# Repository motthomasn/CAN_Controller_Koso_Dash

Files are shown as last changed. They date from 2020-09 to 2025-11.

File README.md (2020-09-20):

# CAN_Controller_Koso_Dash
Teensy 3.2 based controller board designed to recieve engine data from ECU via CAN-Bus and use it to control a Koso RX2N motorcycle dash

This module was built for my CBR250RRi project. The aim was to run my aftermarket Koso RX2N dash using the same sensors (coolant & oil temp) as the ECU to avoid having to double up on sensors. The idea was to recieve all necessary signals from the ECU via CAN-Bus and then have the Teensy replicate the analogue signals that the dash expects.

The Koso RX2N dash has the following possible inputs for indication:
1. Engine speed         - variable frequency square wave signal
1. Vehicle speed        - variable frequency square wave signal
1. Coolant temperature  - thermistor
1. Oil temperature      - thermistor
1. Oil pressure light   - digital on/off signal, low side switch
1. EOBD light           - digital on/off signal, low side switch
1. Neutral light        - digital on/off signal, low side switch
1. Fuel level           - digital on/off signal, low side switch
1. Hi-beam light        - digital on/off signal, high side switch
1. RH Indicator         - digital on/off signal, high side switch
1. LH Indicator         - digital on/off signal, high side switch

The LH/RH indicators, hi-beam, fuel level & neutral signals were all provided directly from the sensors and wire harness. All other signals relied on sensors which would be connected directly to the ECU and therefore required the controller to provide the signals based on data recieved via CAN-Bus.

**Engine & Vehicle Speed**
Although the ECU could provide the required signal directly to the dash using an injector output, I decided to save the ECU output and hand the job over to the dash controller. A 50% duty cycle variable frequency signal is provided by the Teensy switching 12V to gound. The frequency is updated at 50Hz to avoid visible stuttering of the dash needle during fast engine speed ramps. 
A similar tactic as engine speed was employed to the vehicle speed signal apart from the signal being 5V level and the signal frequency is updated at only 5Hz as vehicle speed is displayed on a 7-segment display. 

**Coolant & Oil Temperature**
A pair of digital potentiometers are employed to replicate the thermistor resistance. The R-T curve for the sensors supplied with the RX2N had been provided by Koso tech support. The linear response and resolution of the digital potentiometers means that there could be an error of up to 3°C between the actual and displayed values between 90-110°C temperature. The dash display is only an indication so this level of accuracy is acceptable.

**Oil Pressure Light**
My bike and most others from the 1990's came fitted with an oil pressure switch. The original switch could be connected directly to the dash but as I have replaced the pressure switch with an actual pressure sensor, I have added the possibility of controlling the light via the dash controller. In the current version of the code, the actual oil pressure is compared to a single threshold, so operates the light much the same as the original switch. I plan to update the code to add a varying pressure threshold with engine speed and oil temperature after I have collected some data to build a normal oil pressure map.

**EOBD Light**
The EOBD light is a handy indicator of something being wrong on the ECU side. The measure of "something wrong" depends on the ECU but on my Life Racing F88R I use a flag called *engineEnable* and set the EOBD light if the flag is not equal to 0 (OK).

I included tracks on the controller board for USB to allow the Teensy code to be updated without opening the enclosure. However, I did not adhere to recommendations around USB bus design and so this does not work. I plan to update the board to meet guidelines in the future.

For further details on the CBR250RRi project, refer to the website https://www.cbr250rri.com/.

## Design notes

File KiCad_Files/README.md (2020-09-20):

This folder contains the KiCad files for the Dash Controller Module

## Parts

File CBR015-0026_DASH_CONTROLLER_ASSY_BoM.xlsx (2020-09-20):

Designation | Qty | Description | Value | Manufacturer | Part Number | Package | Supplier | Stock No. / Order Code | Notes | Datasheet
U1 | 1 | Teensy 3.2 |  | PJRC | Teensy 3.2 | PDIP
 | 2 | Teensy Pin Header | 14-way, 2.54mm |  |  |  | RS
 | 2 | Teensy Connector Socket | 14-way, 2.54mm |  |  |  | RS
 | 1 | Teensy USB Pin Header |  |  |  |  | RS
 | 1 | Teensy USB Connector Socket |  |  |  |  | RS
U2 | 1 | 5V Power Regulator | 5V, 1A | Traco Power | TSR-1-2450 | SIP3 | RS | 666-4379
U3 | 1 | CAN Transciever |  | Microchip | MCP2551-I/SN | SOIC-8 | RS | 738-6036
U4 | 1 | Digital Potentiometer | 250K, 1024-posn | Analog Devices | AD5235BRUZ250 | TSSOP-16 | RS | 497-0751
U5, U6 | 2 | Dash Signal & Shift Light Switches | NPN, 40V, 200mA | ON Semiconductor | MMPQ3904 | SOIC-16 | RS | 807-4863
C1 | 1 | Power Reg Cap | 22uF | Murata | GRM219B30G226ME66D | 0805 | RS | 798-4621
C2 | 1 | CAN Transciever Smoothing Cap | 100nF | AVX | 08055C104KAT2A | 0805 | RS | 464-6688
C3 | 1 | Digital Pot Smoothing Cap | 100nF | AVX | 08055C104KAT2A | 0805 | RS | 464-6688
R1 | 1 | CAN Transciever Reset | 18K | TE Connectivity | CRG0805F18K | 0805 | RS | 223-0590
R2 | 1 | CAN Termination | 120 | Panasonic | ERJP06F1200V | 0805 | RS | 721-7674
R3, R4, R5, R6, R7, R8, R13, R14 | 8 | BJT Base Current Limiters | 523 | Panasonic | ERA6AEB5230V | 0805 | RS | 708-6048
R9, R10 | 2 | VSS & TACH Pull-up Resistors | 10K | TE Connectivity | CRG0805F10K | 0805 | RS | 223-0562
R11, R12 | 2 | Pot RDY & CS Pull-up resistors | 2.2K | Vishay | CRCW08052K20FKEA | 0805 | RS | 679-1207
S1 | 1 | CAN Termination Jumper | Single SPST | APEM | IKD0103101 |  | RS | 877-2233
J1 | 1 | Harness Connector | Superseal 1.0, 26-way | TE Connectivity | 6437288-4 |  | RS | 726-7011

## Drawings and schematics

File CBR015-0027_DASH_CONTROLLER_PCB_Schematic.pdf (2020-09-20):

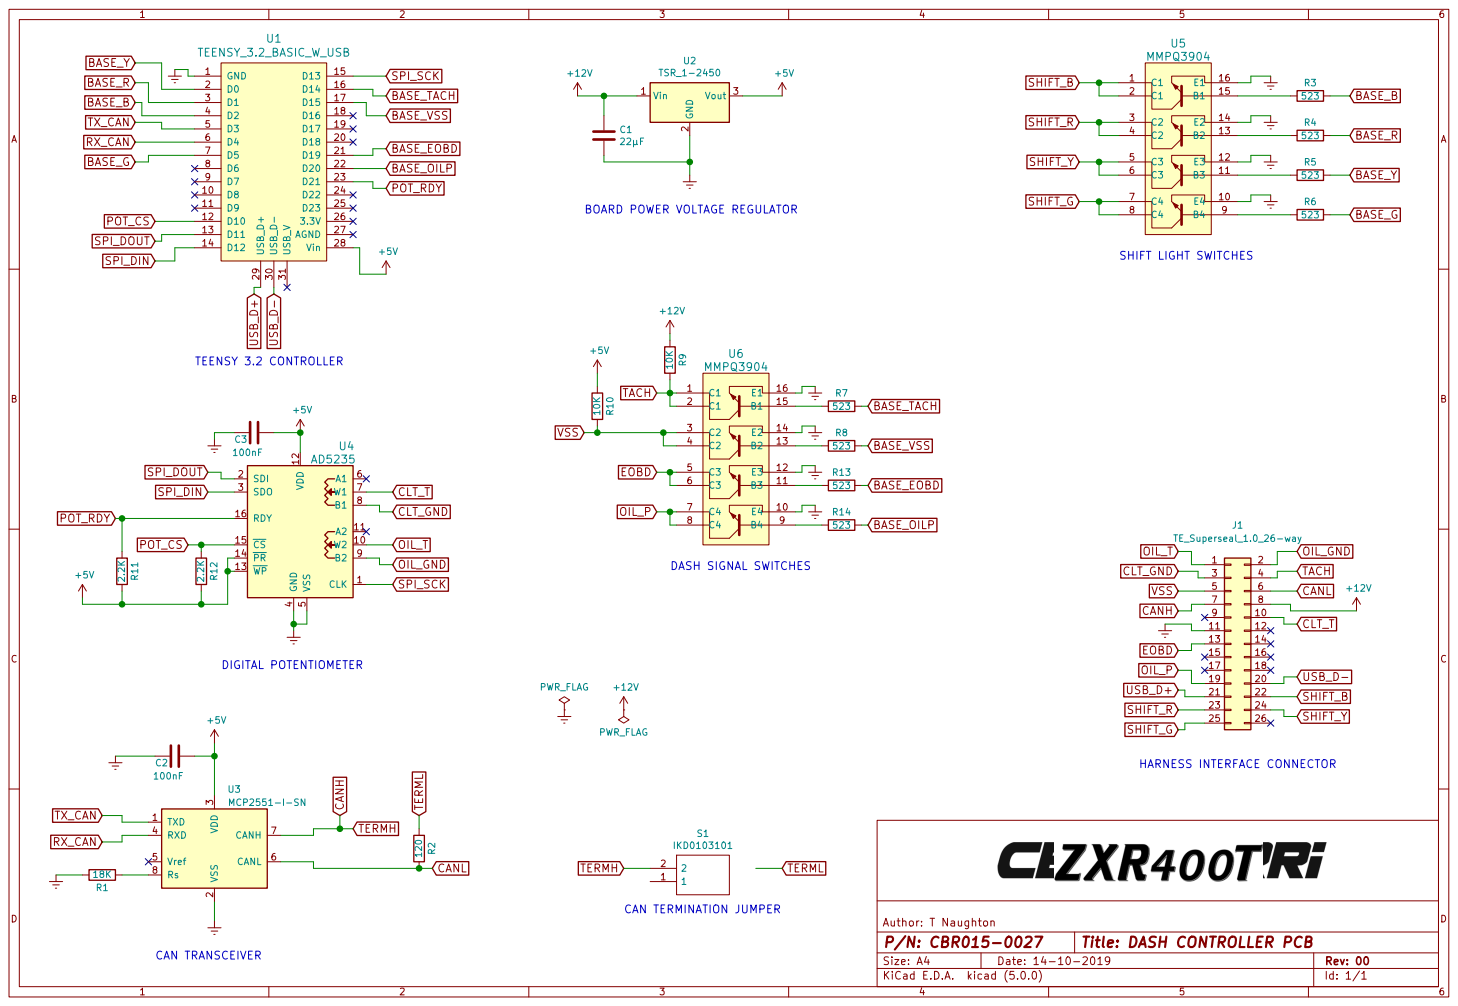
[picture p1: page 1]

BOARD POWER VOLTAGE REGULATOR

3 RXD 4 Vref 5 CANL 6 CANH 7 Rs 8 U3MCP2551-I-SN

Id: 1/1 Title: DASH CONTROLLER PCB

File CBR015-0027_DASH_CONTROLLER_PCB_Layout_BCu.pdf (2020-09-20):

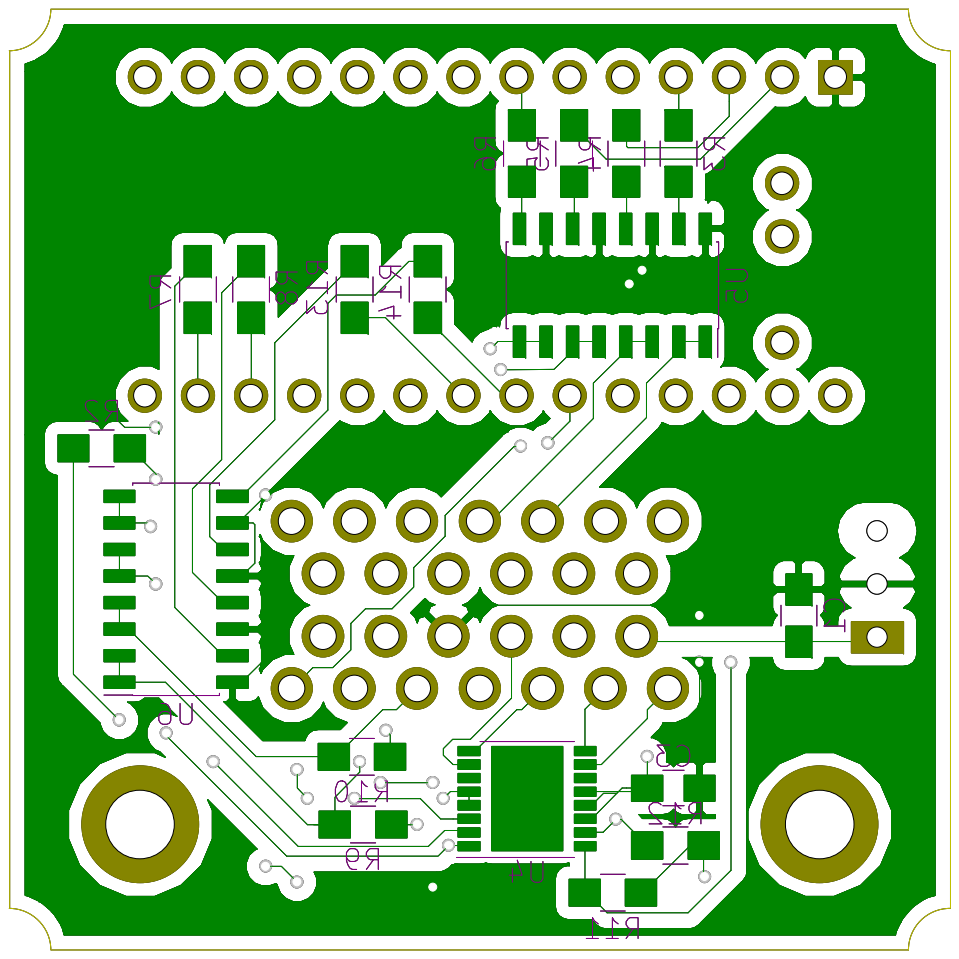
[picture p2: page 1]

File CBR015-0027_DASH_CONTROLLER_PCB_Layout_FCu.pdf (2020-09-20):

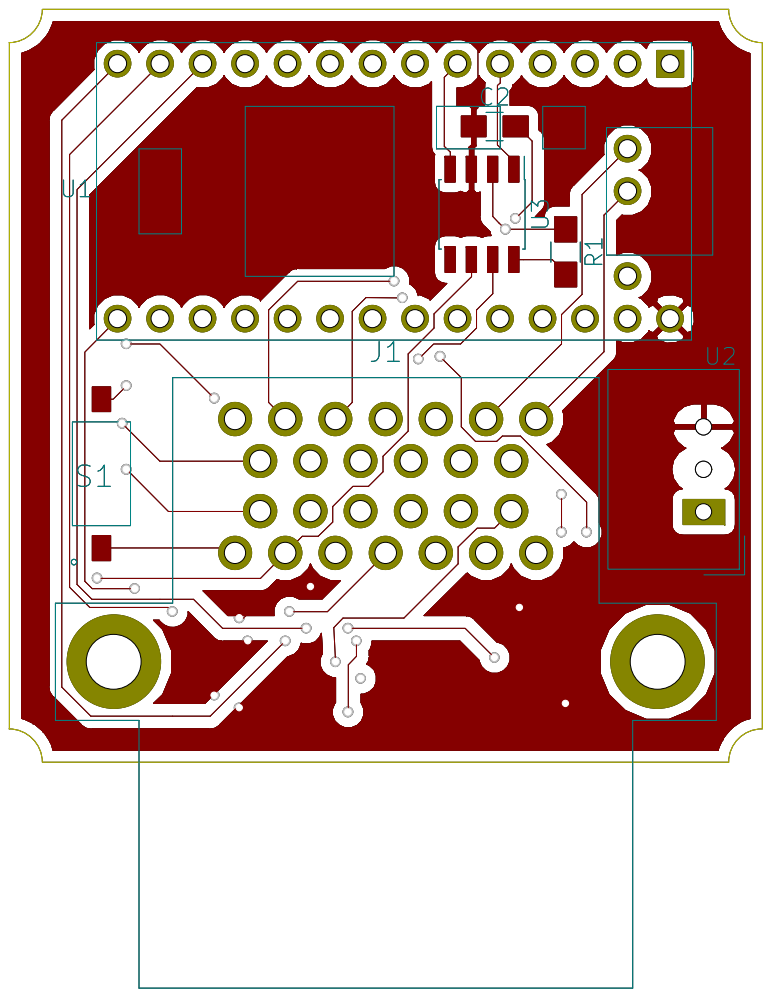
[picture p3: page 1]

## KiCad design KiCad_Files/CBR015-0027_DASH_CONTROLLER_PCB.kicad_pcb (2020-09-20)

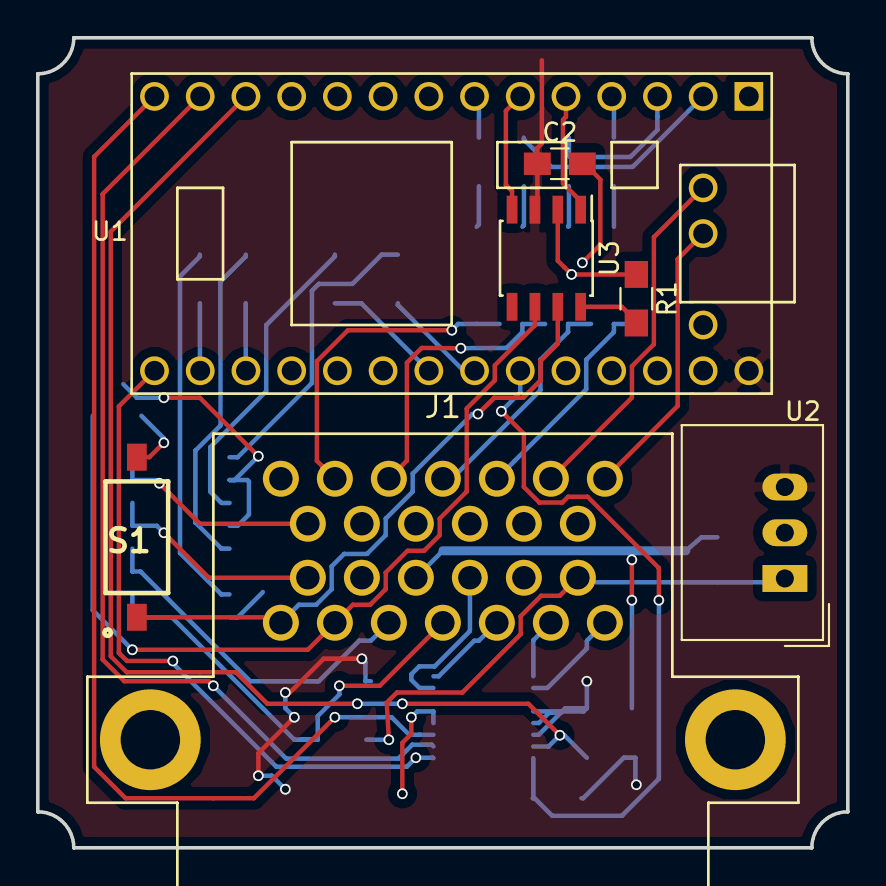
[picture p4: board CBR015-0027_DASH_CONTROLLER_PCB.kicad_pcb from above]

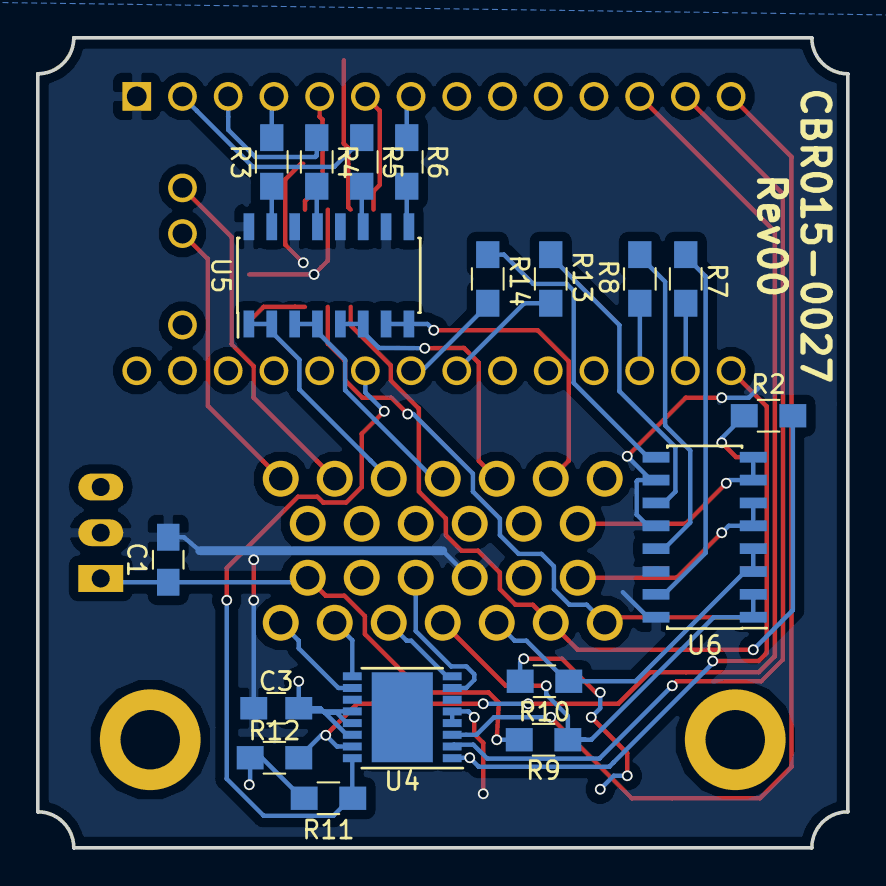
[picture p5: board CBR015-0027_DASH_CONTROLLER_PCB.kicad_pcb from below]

Board: 2 copper layers, 45.0 x 45.0 mm, 25 parts (18 on the bottom side), 44 nets.

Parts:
C1: 22µF; C_0805_HandSoldering
C2, C3: 100nF; C_0805_HandSoldering
J1: Conn_02x13_Odd_Even; TE_SUPERSEAL_1.0_26-WAY
R1: 18K; R_0805_HandSoldering
R2: 120; R_0805_HandSoldering
R3, R4, R5, R6, R7, R8, R13, R14: 523; R_0805_HandSoldering
R9, R10: 10K; R_0805_HandSoldering
R11, R12: 2.2K; R_0805_HandSoldering
S1: IKD0103101
U1: TEENSY_3.2_BASIC_W_USB
U2: TSR_1-2450; DCDC-Conv_TRACO_TSR-1
U3: MCP2551-I-SN; SOIC-8_3.9x4.9mm_Pitch1.27mm
U4: AD5235; HTSSOP-16-1EP_4.4x5mm_Pitch0.65mm
U5, U6: MMPQ3904; SOIC-16_3.9x9.9mm_Pitch1.27mm

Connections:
+5V: C2.1, C3.1, R10.2, R11.1, R12.1, U1.28, U2.3, U3.3, U4.12, U4.13, U4.14
+12V: C1.1, J1.8, R9.2, U2.1
BASE_B: R3.1, U1.4
BASE_EOBD: R13.1, U1.21
BASE_G: R6.1, U1.7
BASE_OILP: R14.1, U1.22
BASE_R: R4.1, U1.3
BASE_TACH: R7.1, U1.16
BASE_VSS: R8.1, U1.17
BASE_Y: R5.1, U1.2
CANH: J1.7, S1.1, U3.7
CANL: J1.6, R2.1, U3.6
CLT_GND: J1.3, U4.8
CLT_T: J1.10, U4.7
EOBD: J1.13, U6.5, U6.6
Earth: C1.2, C2.2, C3.2, J1.11, R1.1, U1.1, U2.2, U3.2, U4.4, U4.5, U5.10, U5.12, U5.14, U5.16, U6.10, U6.12, U6.14, U6.16
unnamed: R1.2, U3.8
unnamed: R3.2, U5.15
unnamed: R4.2, U5.13
unnamed: R5.2, U5.11
unnamed: R6.2, U5.9
unnamed: R7.2, U6.15
unnamed: R8.2, U6.13
unnamed: R13.2, U6.11
unnamed: R14.2, U6.9
OIL_GND: J1.2, U4.9
OIL_P: J1.19, U6.7, U6.8
OIL_T: J1.1, U4.10
POT_CS: R12.2, U1.12, U4.15
POT_RDY: R11.2, U1.23, U4.16
RX_CAN: U1.6, U3.4
SHIFT_B: J1.22, U5.1, U5.2
SHIFT_G: J1.25, U5.7, U5.8
SHIFT_R: J1.23, U5.3, U5.4
SHIFT_Y: J1.24, U5.5, U5.6
SPI_DIN: U1.14, U4.3
SPI_DOUT: U1.13, U4.2
SPI_SCK: U1.15, U4.1
TACH: J1.4, R9.1, U6.1, U6.2
TERML: R2.2, S1.2
TX_CAN: U1.5, U3.1
USB_D+: J1.21, U1.29
USB_D-: J1.20, U1.30
VSS: J1.5, R10.1, U6.3, U6.4

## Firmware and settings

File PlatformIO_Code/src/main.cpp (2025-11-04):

/*
 * Copyright 2020 THOMAS NAUGHTON
 * 
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
 * The above copyright notice and this permission notice shall be included in all copies or substantial portions of the Software.
 * 
 * THE SOFTWARE IS PROVIDED "AS IS", WITHOUT WARRANTY OF ANY KIND, EXPRESS OR IMPLIED, INCLUDING BUT NOT LIMITED TO THE WARRANTIES OF MERCHANTABILITY, 
 * FITNESS FOR A PARTICULAR PURPOSE AND NONINFRINGEMENT. IN NO EVENT SHALL THE AUTHORS OR COPYRIGHT HOLDERS BE LIABLE FOR ANY CLAIM, DAMAGES OR OTHER LIABILITY, 
 * WHETHER IN AN ACTION OF CONTRACT, TORT OR OTHERWISE, ARISING FROM, OUT OF OR IN CONNECTION WITH THE SOFTWARE OR THE USE OR OTHER DEALINGS IN THE SOFTWARE.
 */

/*
 * CBR015-0026_DASH_CONTROLLER_ASSY_CODE
 * Version 1.0  03-06-2020
 * Version 2.0  05-06-2023      CAN IDs updated to match CAN config v3.0
 *                              Shift lights functionality added
 * Version 3.0  29-10-2023      Code adjusted to suit Rev02 PCB layout & functionality
 *                              CAN Rx adjusted to match CAN config v3.1
 *                              Selectable measurement display in place of vehicle speed
 *                              Auto adjustment of shift light LED brighness depending on ambient light conditions
 *                              Added CAN transmission of light intensity value and LED PWM duty cycle
 * Version 3.1  04-11-2025      Added shift lights test mode via CAN message     
 * 
 * 
 * This code is designed for use with the CBR015-0026 DASH CONTROLLER ASSY utilising CBR015-0027 Rev02 PCB layout
 * CAN Config: CBR250RRi_CAN_CONFIG_v3.6.dbc
 * Messages recieved via CAN are MSB First or Big Endian byte order
 * 
 * See documentation for details & overview
 */

#include <Arduino.h>
#include <FlexCAN.h>
#include <SPI.h>
#include <CircularBuffer.hpp>

// ===============================================================================================================
// Declare constants most likely to be adjusted by user in this block

#define TACHUpdatePeriod 20000      // Tach output update rate in µs
#define VSSUpdatePeriod 200000      // VSS output update rate in µs
#define IndUpdatePeriod 500000      // Indicators output update rate in µs
#define can_speed 500000            // CAN-Bus baud rate in bps

#define RPMmin 50                   // minimum engine speed before outputting signal
#define VSSmin 1                    // minimum vehicle speed before outputting signal in kph
#define circ 2                      // tyre circumference in metres
#define pulses 4                    // VSS pulses per rev

#define SHIFTUpdatePeriod 50000     // Shift lights state update rate in µs
#define SHIFTFlashPeriod 50000      // Shift lights flash rate in µs
#define brightnessCheck 1000000     // Frequncy to check ambient light brightness in µs, 1s
#define SHIFTGstage 1               // changeLightStage to switch on green shift light
#define SHIFTYstage 2               // changeLightStage to switch on yellow shift light
#define SHIFTRstage 3               // changeLightStage to switch on red shift light
#define SHIFTBstage 4               // changeLightStage to switch on blue shift light
#define SHIFTFstage 5               // changeLightStage to flash shift lights

// ===============================================================================================================

// Declare SPI pin numbers according to CBR015-0027 Rev00 schematic
#define chipSelect 10
#define mosi 11
#define miso 12
#define sck 13

// Declare other output pins according to CBR015-0027 Rev00 schematic
#define TACHpin 14
#define VSSpin 15
#define EOBDpin 19
#define OILPpin 20
#define SHIFTGpin 9
#define SHIFTYpin 6
#define SHIFTRpin 5
#define SHIFTBpin 23
#define LIGHTpin A3
#define ROTARY1pin 8
#define ROTARY2pin 16

// Define light to LED brightness relationship
#define LIGHT_BUFFER_SIZE 5   // Buffer 5 brightness readings
#define darkness 17           // light sensor reading corresponding to darkness (min 0)
#define sunlight 734          // light sensor reading corresponding to bright sunlight (max 1023)
#define dimLED 1              // LED PWM duty for darkness (min 0)
#define brightLED 255         // LED PWM duty for direct sunlight (max 255)

// Declare can bus and can messages
static CAN_message_t rxmsg;
// only interested in IDs 0x100, 0x101, 0x250, 0x7F0
#define filterID1 0x000
#define maskID1 0x4AE
#define filterID2 0x7F0
#define maskID2 0x7FF
#define txID 0x750      // message ID for light intensity value
static CAN_message_t txmsg;

// Declare variables used by timers
uint32_t currentMicros;
uint32_t PrevTACHUpdateMicros=0, PrevVSSUpdateMicros=0, PrevIndUpdateMicros=0, PrevSHIFTUpdateMicros=0, PrevSHIFTFlashMicros=0, PrevBrightCheckMicros=0, PrevCANtxMicros=0;

// Declare variables used by dig out pins
// TACH
bool TACHpinState = LOW;
uint32_t previousTACHpinMicros=0, TACHperiod=UINT32_MAX;
int16_t RPM=0;

// VSS
bool VSSpinState = LOW;
uint32_t previousVSSpinMicros=0, VSSperiod=UINT32_MAX;
float facVSSperiod;
uint8_t VSS=0, *VSSdisp;

// EOBD
uint8_t engineEnable=0; // initialise at 0 => OK
bool EOBDpinState=LOW;

// OILP
bool OILPpinState=LOW;
uint8_t lowEopLight=0; // initialise at 0 => OFF

// Shift Lights
uint8_t changeLightStage=0, ledPWM=0;
uint16_t ambLight;
CircularBuffer<uint16_t, LIGHT_BUFFER_SIZE> lightBuffer;
bool shiftGState=LOW, shiftYState=LOW, shiftRState=LOW, shiftBState=LOW, shiftFlashState=LOW, shiftTest=false;

float ECT, EOT;
uint8_t TPS=0, GEAR=2;

// Declare AD5235
// Source: https://forum.arduino.cc/index.php?topic=356088.0
// based on code provided by GROZEA Ion
//www.grozeaion.com
//Control Registers
#define CMD__NOTHING B00000000 //0  - Do nothing
#define CMD_MEM2RDAC B00010000 //1  - Restore EEMEM (A0) contents to RDAC (A0) register. See Table 16.
#define CMD_RDAC2MEM B00100000 //2  - Store wiper setting. Store RDAC (A0) setting to EEMEM (A0). See Table 15. - Use a delay of 50ms!!!
#define CMD_USER2MEM B00110000 //3  - Store contents of Serial Register Data Byte 0 and Serial Register Data Bytes 1 (total 16 bits) to EEMEM (ADDR). See Table 18.- Use a delay of 50ms!!!
#define CMD_DECRE6DB B01000000 //4  - Decrement by 6 dB. Right-shift contents of RDAC (A0) register, stop at all 0s.
#define CMD_DEALL6DB B01010000 //5  - Decrement all by 6 dB. Right-shift contents of all RDAC registers, stop at all 0s.
#define CMD_DECR1STP B01100000 //6  - Decrement contents of RDAC (A0) by 1, stop at all 0s.
#define CMD_DECA1STP B01110000 //7  - Decrement contents of all RDAC registers by 1, stop at all 0s.
#define CMD_ALL2RDAC B10000000 //8  - Reset. Refresh all RDACs with their corresponding EEMEM previously stored values. - Use a delay of 30us!!!
#define CMD_GETEMEM B10010000  //9  - Read contents of EEMEM (ADDR) from SDO output in the next frame. See Table 19. - Use a delay of 30us!!!
#define CMD_GET_RDAC B10100000 //10 - Read RDAC wiper setting from SDO output in the next frame. See Table 20. - Use a delay of 30us!!!
#define CMD_SET_RDAC B10110000 //11 - Write contents of Serial Register Data Byte 0 and Serial Register Data Byte 1 (total 10 bits) to RDAC (A0). See Table 14.
#define CMD_INCRE6DB B11000000 //12 - Increment by 6 dB: Left-shift contents of RDAC (A0),stop at all 1s. See Table 17.
#define CMD_INALL6DB B11010000 //13 - Increment all by 6 dB. Left-shift contents of all RDAC registers, stop at all 1s.
#define CMD_INCR1STP B11100000 //14 - Increment contents of RDAC (A0) by 1, stop at all 1s. See Table 15.
#define CMD_IALL1STP B11000000 //15 - Increment contents of all RDAC registers by 1, stop at all 1s.

SPISettings settingsA(4000000, MSBFIRST, SPI_MODE0); // Default setting: 4MHz bus speed, MSB first byte order & Mode0

#define ECTwiper 0    // ECT pot is wiper 0
#define EOTwiper 1    // EOT pot is wiper 1
#define Beta 4005.678 // beta value for Koso BF030000 sensor between 25-100degC
#define R0 49120      // Ohms
#define T0 298.15     // degK
float logR2, R2, ECTResistance, EOTResistance, Rmin, AD5235inECT, AD5235inEOT;
uint8_t myVal = 0;
// Steinhart-Hart constants for Koso BF030000 sensor
//#define c1 0.007579331099
//#define c2 0.0002332380527
//#define c3 0.00000006080582592

// ===============================================================================================================
uint8_t transferData(uint8_t data)
{
  SPDR = data;                  // send the data
  while (!(SPSR & (1 << SPIF))) // wait until transmission is complete
    ;
  return SPDR;
}

// ===============================================================================================================
uint8_t PT65112(uint8_t pin1, uint8_t pin2)
{
  // function to read state of PT65112 rotary switch
  pinMode(pin1, INPUT_PULLUP);
  pinMode(pin2, INPUT_PULLUP);
  bool state1 = !digitalRead(pin1); // invert truthism here as pins are active when pulled low
  bool state2 = !digitalRead(pin2);

  return state1 | (state2<<1);

}

union uint16_split {
  uint16_t value;
  uint8_t bytes[2];
};

// ===============================================================================================================
void setWiper(uint8_t w, uint16_t value)
{
  //SPI.beginTransaction(settingsA); // allow access to SPI bus
  digitalWrite(chipSelect, LOW); // pull CS low
  myVal = transferData(CMD_SET_RDAC + w);
  myVal = transferData(value >> 8);
  myVal = transferData(value & 0xFF);
  digitalWrite(chipSelect, HIGH); // set CS high
  //SPI.endTransaction(); // remove access to SPI bus
}

// ===============================================================================================================
void can_recieve()
{

  if (Can0.available())
  {

    Can0.read(rxmsg);

    switch (rxmsg.id)
    {

    case 0x100:
      RPM = ((int16_t((rxmsg.buf[1]) | (rxmsg.buf[0] << 8))));         //rpm
      VSS = uint8_t(round((int16_t((rxmsg.buf[3]) | (rxmsg.buf[2] << 8))) * 0.036)); //kph No decimal place display on speedometer
      break;
    case 0x101:
      if (!shiftTest)
      {
        // ignore changeLightStage from ECU if test mode active
        changeLightStage = uint8_t(rxmsg.buf[1]); 
      }
      // changeLightState = uint8_t(rxmsg.buf[3]);
      lowEopLight = uint8_t(rxmsg.buf[5]);
      engineEnable = uint8_t(rxmsg.buf[7]);
      break;
    case 0x250:
      ECT = ((int16_t((rxmsg.buf[1]) | (rxmsg.buf[0] << 8))) * 0.1); //degC
      EOT = ((int16_t((rxmsg.buf[3]) | (rxmsg.buf[2] << 8))) * 0.1); //degC
      TPS = uint8_t(round((int16_t((rxmsg.buf[5]) | (rxmsg.buf[4] << 8))) * 0.012207031)); //% No decimal place display on speedometer
      GEAR = uint8_t(rxmsg.buf[7]);
      break;
    case 0x7F0:
      shiftTest = bool( 1 & rxmsg.buf[0] ); // bitwise AND to extract bit 0
      if (shiftTest)
      {
        // update changeLightStage from tester message if bit0 active
        changeLightStage = uint8_t(rxmsg.buf[0] >> 1); // right shift by 1 to remove bit 0 request
      }
    }
  }
}

// ===============================================================================================================
// CAN Send
void CANsend()
{
  uint16_split light;
  light.value = ambLight;

  // ID 0x750
  txmsg.buf[1] = light.bytes[0]; // LSB
  txmsg.buf[0] = light.bytes[1]; // MSB

  txmsg.buf[2] = ledPWM;

  Can0.write(txmsg);
}
// ===============================================================================================================
void shiftLBrightness()
{
  uint16_t lightReading = analogRead(LIGHTpin); // read light sensor pin

  // add light reading to buffer. Buffer is used because there is a lot of variance in the light readings.
  // i.e. shining a bright LED light directly at the sensor provides a generally high reading of ~1010 but these readings are often interspersed with readings of ~30 for 1 or 2 readings in between
  lightBuffer.push(lightReading); 

  ambLight = 0; // init
  for (decltype(lightBuffer)::index_t i = 0; i < lightBuffer.size(); i++) {
    // mathematically, max(a+b) = ( (a+b) + |(a-b)| ) / 2
    ambLight = ( (ambLight+lightBuffer[i]) + abs((ambLight-lightBuffer[i])) ) / 2;
  }

  // Serial.print("Brightness reading: ");
  // Serial.println(lightReading);
  // Serial.print("Brightness buffer max: ");
  // Serial.println(ambLight);

  ambLight = constrain(ambLight, darkness, sunlight); // constrain readings to predefined limits

  ledPWM = map(ambLight, darkness, sunlight, dimLED, brightLED); // determine corresponding PWM duty

  CANsend();
}

// ===============================================================================================================
void UpdateIndicators()
{

  // check oil pressure and set pin state
  if ( ( (lowEopLight == 1) || (engineEnable == 100) ) && (OILPpinState == LOW) )
  {
    // only change & write pin state if required
    OILPpinState = HIGH;
    digitalWrite(OILPpin, OILPpinState);
  }
  else if ( (lowEopLight == 0) && (engineEnable != 100) && (OILPpinState == HIGH) )
  {
    OILPpinState = LOW;
    digitalWrite(OILPpin, OILPpinState);
  }

  // check engine enable state and set pin state
  if ((engineEnable > 0) && (EOBDpinState == LOW))
  {
    // only change & write pin state if required
    EOBDpinState = HIGH;
    digitalWrite(EOBDpin, EOBDpinState);
  }
  else if ((engineEnable == 0) && (EOBDpinState == HIGH))
  {
    EOBDpinState = LOW;
    digitalWrite(EOBDpin, EOBDpinState);
  }

  // update coolant temp & get digital pot ADC request
  ECT = ECT + 273.15; // convert to degK

  ECTResistance = R0 * (exp(Beta * ((1.0 / ECT) - (1.0 / T0)))); //Ohms

  AD5235inECT = (ECTResistance - Rmin) * (1024 - 1) / (250000 - Rmin) + 1; // same as map function but gives float output

  AD5235inECT = round(AD5235inECT); // round to nearest whole number

  // update oil temp & get digital pot ADC request
  EOT = EOT + 273.15; // convert to degK

  EOTResistance = R0 * (exp(Beta * ((1.0 / EOT) - (1.0 / T0)))); // Ohms

  AD5235inEOT = (EOTResistance - Rmin) * (1024 - 1) / (250000 - Rmin) + 1; // same as map function but gives float output

  AD5235inEOT = round(AD5235inEOT); // round to nearest whole number

  // Send ADC values to AD5235
  setWiper(ECTwiper, AD5235inECT);
  setWiper(EOTwiper, AD5235inEOT);
}

// ===============================================================================================================
void TACHpulse()
{

  TACHpinState = !TACHpinState; // switch state of pin
  digitalWrite(TACHpin, TACHpinState);
}

// ===============================================================================================================
void VSSpulse()
{

  VSSpinState = !VSSpinState; // switch state of pin
  digitalWrite(VSSpin, VSSpinState);
}

// ===============================================================================================================
void TACHupdate()
{

  // calculate timer period for pulses
  // RPM
  if (RPM < RPMmin)
  {
    TACHperiod = UINT32_MAX; // set period to max possible to avoid triggering
  }
  else
  {
    TACHperiod = (30000000 / RPM); // Should match Screen 7, P - 1, High impulse.
  }
}

// ===============================================================================================================
void VSSupdate()
{

  // calculate timer period for pulses
  // VSS
  if (*VSSdisp <= VSSmin)
  {
    VSSperiod = UINT32_MAX;
  }
  else
  {
    VSSperiod = facVSSperiod / *VSSdisp;
  }
}

// ===============================================================================================================
void shiftLightsFlash()
{
  // flashes all shift lights
  shiftFlashState = !shiftFlashState; // switch state
  shiftGState = shiftFlashState;
  shiftYState = shiftFlashState;
  shiftRState = shiftFlashState;
  shiftBState = shiftFlashState;

  uint8_t pwm;

  if (shiftFlashState==HIGH)
  {
    pwm = ledPWM;
  }
  else
  {
    pwm = 0;
  }

  analogWrite(SHIFTGpin, pwm);
  analogWrite(SHIFTYpin, pwm);
  analogWrite(SHIFTRpin, pwm);
  analogWrite(SHIFTBpin, pwm);
  
}

// ===============================================================================================================
void shiftLights()
{
  // Flash
  if (changeLightStage >= SHIFTFstage) {
    if (currentMicros - PrevSHIFTFlashMicros > SHIFTFlashPeriod)
    {
      PrevSHIFTFlashMicros = currentMicros;
      shiftLightsFlash();
    }
  }
  else {
    shiftFlashState = LOW;

    // Green
    if ( (changeLightStage >= SHIFTGstage) && (shiftGState==LOW) ) {
      shiftGState = HIGH;
      analogWrite(SHIFTGpin, ledPWM);
    }
    else if ( (changeLightStage < SHIFTGstage) && (shiftGState==HIGH) ) {
      shiftGState = LOW;
      analogWrite(SHIFTGpin, 0);
    }

    // Yellow
    if ( (changeLightStage >= SHIFTYstage) && (shiftYState==LOW) ) {
      shiftYState = HIGH;
      analogWrite(SHIFTYpin, ledPWM);
    }
    else if ( (changeLightStage < SHIFTYstage) && (shiftYState==HIGH) ) {
      shiftYState = LOW;
      analogWrite(SHIFTYpin, 0);
    }

    // Red
    if ( (changeLightStage >= SHIFTRstage) && (shiftRState==LOW) ) {
      shiftRState = HIGH;
      analogWrite(SHIFTRpin, ledPWM);
    }
    else if ( (changeLightStage < SHIFTRstage) && (shiftRState==HIGH) ) {
      shiftRState = LOW;
      analogWrite(SHIFTRpin, 0);
    }

    // Blue
    if ( (changeLightStage >= SHIFTBstage) && (shiftBState==LOW) ) {
      shiftBState = HIGH;
      analogWrite(SHIFTBpin, ledPWM);
    }
    else if ( (changeLightStage < SHIFTBstage) && (shiftBState==HIGH) ) {
      shiftBState = LOW;
      analogWrite(SHIFTBpin, 0);
    }
  }
}

// ===============================================================================================================
void setup()
{
  delay(5000);
  // Serial.begin(115200); // only used for USB debugging

  // CAN setup
  CAN_filter_t filter1;
  filter1.id = filterID1;
  filter1.ext = 0; //defines if filter is extended or standard frame. 0 = std, 1 = extended
  filter1.rtr = 0;

  CAN_filter_t filter2;
  filter2.id = filterID2;
  filter2.ext = 0; //defines if filter is extended or standard frame. 0 = std, 1 = extended
  filter2.rtr = 0;

  Can0.begin(can_speed);

  Can0.setMask(maskID2 << 18, 0); //bitshift is necessary for 11-bit id's
  Can0.setFilter(filter2, 0);

  // all filters must be populated so just set the remaining ones the same
  for (uint8_t filterNum = 1; filterNum < 14; filterNum++)
  {
    Can0.setMask(maskID1 << 18, filterNum); //bitshift is necessary for 11-bit id's
    Can0.setFilter(filter1, filterNum);
  }

  // SPI Setup
  SPI.setMOSI(mosi);
  SPI.setMISO(miso);
  SPI.setSCK(sck);
  pinMode(chipSelect, OUTPUT);
  SPI.begin();

  // Digital Pins Setup
  pinMode(TACHpin, OUTPUT);
  pinMode(VSSpin, OUTPUT);
  pinMode(EOBDpin, OUTPUT);
  pinMode(OILPpin, OUTPUT);
  pinMode(SHIFTGpin, OUTPUT);
  pinMode(SHIFTYpin, OUTPUT);
  pinMode(SHIFTRpin, OUTPUT);
  pinMode(SHIFTBpin, OUTPUT);
  pinMode(LIGHTpin, INPUT);

  // Read state of rotary switch & point to different variable depending on state.
  uint8_t swtState = PT65112(ROTARY1pin, ROTARY2pin);
  // Serial.print("Switch state: ");
  // Serial.println(swtState); // swtState not working. Always shows 0

  switch (swtState)
  {
    case 0:
      VSSdisp = &VSS;
      break;
    case 1:
      VSSdisp = &GEAR;
      break;
    case 2:
      VSSdisp = &TPS;
      break;
  }

  // calculate min resistance for AD5235
  Rmin = 250000.0 / 1024.0;

  // calculate factor to convert VSS to required pulse period
  facVSSperiod = ( ( 1800000 * circ ) / pulses );

  txmsg.id = txID;
  txmsg.len = 8;

  // get required shift lights brightness before entering loops
  shiftLBrightness();

}

// ===============================================================================================================
void loop()
{

  can_recieve(); // Carry out CAN recieve function as often as possible

  currentMicros = micros();

  // Debug only
  //Serial.print("rpm: ");
  //Serial.println(RPM);

  if (currentMicros - previousTACHpinMicros > TACHperiod)
  {
    previousTACHpinMicros = currentMicros;
    TACHpulse();
  }
  if (currentMicros - previousVSSpinMicros > VSSperiod)
  {
    previousVSSpinMicros = currentMicros;
    VSSpulse();
  }
  if (currentMicros - PrevTACHUpdateMicros > TACHUpdatePeriod)
  {
    PrevTACHUpdateMicros = currentMicros;
    TACHupdate();
  }
  if (currentMicros - PrevVSSUpdateMicros > VSSUpdatePeriod)
  {
    PrevVSSUpdateMicros = currentMicros;
    VSSupdate();
  }
  if (currentMicros - PrevSHIFTUpdateMicros > SHIFTUpdatePeriod) 
  {
    PrevSHIFTUpdateMicros = currentMicros;
    // Serial.print("Test active: ");
    // Serial.println(shiftTest);
    // Serial.print("Shift light stage: ");
    // Serial.println(changeLightStage);

    shiftLights();
  }
  if (currentMicros - PrevIndUpdateMicros > IndUpdatePeriod)
  {
    PrevIndUpdateMicros = currentMicros;
    // Debug only
    //Serial.print("vss: ");
    //Serial.println(VSS);
    //Serial.print("ect: ");
    //Serial.println(ECT);
    //Serial.print("EOT: ");
    //Serial.println(EOT);
    //Serial.print("EngineEnable: ");
    //Serial.println(engineEnable);
    //Serial.print("EOP: ");
    //Serial.println(OILP);
    // End Debug
    UpdateIndicators();
  }
  if (currentMicros - PrevBrightCheckMicros > brightnessCheck)
  {
    PrevBrightCheckMicros = currentMicros;

    shiftLBrightness();
  }
}
